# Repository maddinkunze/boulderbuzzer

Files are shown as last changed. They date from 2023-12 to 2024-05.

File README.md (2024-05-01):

# boulderbuzzer - Buzzers that can be mounted to (portable) boulder walls

This repository contains information, source code, pcb designs, assembly instructions, etc for building the following buzzers:

Those buzzers are designed around hollow M10 bolts that can be used to simultaneously mount the buzzer to a (in my case portable) boulder wall whilst allowing power cables to pass through the back and neatly hidden away.

## Buzzer

The [buzzer subdirectory](buzzer) contains some docs, the pcb design, the source code, some 3d-printable files and a few words about assembly, disassembly and repair for/of an individual buzzer.

## Station

The [station subdirectory](station) contains the documentation and source code for the base station to which all buzzers connect.

## Troubleshooting

1. **General:** What seems to be faulty?
   - Power Supply: Replace your power supply. It should provide 4.5V-5.5V and at least 0.5A + anything you want to switch on when pressing a buzzer (external ports). If possible, only connect one thing per power supply
   - Station: Repair the station as described here: [TODO]
   - All Buzzers: It is probably the station, do what the option "Station" says
   - One Buzzer: Go to step 2 (Buzzer/Startup)
2. **Buzzer/Startup:** Which color(s) does the buzzer have when power is supplied?
   - None: The buzzer (specifically the power plug/cable, the voltage regulator or the microcontroller) is probably faulty, go to step 3 (Buzzer/Faulty)
   - Blue (pulsating): Try to restart the station by unplugging it. It still does not work? The station is probably faulty, go back to step 1 (General)
   - Green (3 blinks): The buzzer is connected, go to step 4 (Buzzer/Press)
3. **Buzzer/Faulty:** Unplug everything and only plug in the station and the one "faulty" buzzer. Try to use the power cable of a different buzzer. Does the buzzer behave differently?
   - Yes: Go to step 2 (Buzzer/Startup). You have been here already and are going around in circles? Do what the option "No" says.
   - No: The buzzer is probably faulty. Repair the buzzer as described [here](buzzer#disassembly-and-repair)
4. **Buzzer/Press:** Press the buzzer after it is connected. What happens?
   - Nothing: the buzzer (specifically the microcontroller or button) is probably faulty, go to step 3 (Buzzer/Faulty)
   - It blinks red for half a second and turns off: There is probably another buzzer active and the game is working as intended. You have checked that already and it is not the intended behaviour (i.e. only one buzzer connected)? Then go to step 3 (Buzzer/Faulty)
   - It or another buzzer turned on or changed color: The buzzer probably works as intended. Go to step 5 (Buzzer/Working)
5. **Buzzer/Working:** Try to connect everything back one by one. Does it stop working at some point?
   - Yes: Inspect the last thing you've connected before it stopped working. Try to fix the last thing you've connected before it stopped working by going to step 1 (General). Did you try this with multiple things and at some random point it stopped working but it could not be associated with one specific device? Your power supply is probably not powerful enough. Go back to step 1 (General) and assume the power supply is the fault.
   - No: You've fixed it by restarting it i guess. Yay

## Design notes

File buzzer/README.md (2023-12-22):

# Buzzer

## Build Instructions

### Bill of Materials

| Amount | Part Name | DIY | Buy | Image | Additional Notes |
|---|---|---|---|---|---|
| $1 \times$ | Buzzer | ❌ | https://www.amazon.com/dp/B0CPHT5N3X <br> https://www.ebay.com/itm/395040810324 <br> https://www.amazon.com/dp/B0CGHFH3M1 <br> https://www.amazon.com/dp/B0CQSXBK7R <br> https://www.sparkfun.com/products/9181 <br> https://grobotronics.com/big-dome-push-button-red-100mm.html?sl=en <br> https://www.sparkfun.com/products/retired/11964 | | Preferrably with a transparent or white dome
| $1 \times$ | Buzzer Case | Click here | ❌ | | May not be neccessary, you can repurpose the outer shell of the buzzer
| $1 \times$ | 3D-Printed Bolt Holder | Click here | Can be ordered online using the design files | | Can be omitted in certain cases, should match the type of hollow M10 Bolt you are using
| $1 \times$ | M10 $\times$ 30mm Bolt (Hollow) | Click here | https://www.amazon.de/dp/B0BRNBQY3Y <br> https://www.ebay.com/itm/143405833724 | |
| $2 \times$ | M3 $\times$ 10mm Bolt (countersunk) |
| $2 \times$ | M3 $\times$ 12mm Bolt (countersunk) |
| $2 \times$ | M3 Nut |
| $2 \times$ | M3 Washer |
| $2 \times$ | M3 Rivet Nut | Click here | https://www.amazon.com/dp/B0962QQGFZ <br> https://www.ebay.com/itm/151788854026 | | Should have a height of at least [TODO]mm (so that the spring has enough room for actually compressing so the buzzer can be pressed)
| $2 \times$ | $6-8mm \times 14-20mm$ Compression Spring | Click here | | | The springs of some battery terminals work quite well here
| $1 \times$ | Custom PCB | Click here | The custom PCB can be ordered online (non-exhaustive list) from: <br> https://pcbway.com/ <br> https://jlcpcb.com/
| $2 \times$ | ESP-01S Module | ❌ | https://www.amazon.com/dp/B09J2KPHTN <br> https://www.ebay.com/itm/334980650665 | | An ESP-01S is preferred over an ESP-01, but both can be used
| $1 \times$ | AMS1117-3.3V Voltage Regulator (SMD) | ❌ | https://www.amazon.com/dp/B07X75XXYL <br> https://www.ebay.com/itm/392097419034
| $2 \times$ | RGB LED (5050 SMD) | ❌ | https://www.amazon.com/dp/B01CUGABPU <br> https://www.ebay.com/itm/191674244800 | | The RGB LEDs should not have a common cathode, having individual anodes for each internal LED is preferred but not neccessary; WS2812B and other addressable LEDs are **NOT** supported by my PCB design
| $2 \times$ | 100 - 200 $\Omega$ Resistor (THT)
| $1 \times$ | 120 - 220 $\Omega$ Resistor (THT)
| $1 \times$ | 3.3 - 10 $k\Omega$ Resistor (THT)
| $1 \times$ | 2 Pin, 3.5mm Pitch Screw Terminal (THT) | ❌ | https://www.amazon.com/dp/B07B791NMQ <br> https://www.ebay.com/itm/195773785709 <br> https://www.ebay.com/itm/314913808536 | | This can be omitted when soldering the power cable directly to the PCB; a larger or smaller pitch terminal can be used by changing the pcb design files
| $2 \times$ | 4 Pin, 2.54mm Pitch Round Female Pin Header/Socket (THT) | ❌ | https://www.amazon.com/dp/B0778TFL39 <br> https://www.ebay.com/itm/285532509511 <br> https://www.ebay.com/itm/196038438582 | | This can be omitted or replaced with other types of headers; in _both_ cases the pcb design should be changed
| $1 \times$ | $5.5mm \times 2.1mm$ DC Power Plug | ❌ | https://www.amazon.com/dp/B07Y8M8TWM <br> https://www.ebay.com/itm/114822858070 | | You can chose any plug you want, bear in mind that the plug has to fit through the same $\varnothing 10mm$ hole as the bolt
| $20cm$ | Flexible Power Cable
| $3cm$ | $\varnothing 9-14mm$ Heatshrink | | | | The heatshrink is only needed when removing the cover of your DC plug
| $5ml$ | White (Acrylic) Paint

### Required Tools
 - Screwdriver
   - Bit for your M3 Bolts
   - Bit for your screw terminal (optional)
 - Power Drill
   - 3mm Drill Bit
   - 10mm Drill Bit
 - Paint Brush
 - Soldering Iron + Solder
 - Pair of Pliers (probably)

## Assembly

[TODO]

## Disassembly and Repair

The buzzer contains moving/compliant parts and will be subject to breaking eventually. Here is how you can disassemble and repair the buzzer:

### 1. Undo the marked bolts

When you turn the buzzer around to the side where the cable comes out, there should be 4 bolts and whoever assembled it marked two opposing bolts. Undo these two bolts; the dome/springy part of the buzzer can now be taken out by pushing the hollow bolt/cable through the hole.

### 2. Take off the dome

Take a slim screwdriver or something else to pry and stick it between the lower and upper white parts. Use the screwdriver to pry these two pieces apart. You should be able to see a PCB now.

### 3. Take out the PCB

If possible, detach the power cable by unscrewing the bolts in the terminal block. Undo the two bolts securing the PCB to those long rivet nuts. Make sure you do not lose the rivet nuts or springs. Ideally, you now have only the PCB left and can start to test or resolder any component.

### 4. Take off the microcontroller

Should you need to take out the microcontroller (the extra pcb that kind of sticks up in the air), use pliers to gently wiggle it out of its socket. Try not to bend any of its pins. You can test and/or reprogram the microcontroller (look up "ESP-01" for more information) using the Arduino IDE.

### 5. Find the destroyed component

Please refer to the schematic [below](#schematic) on how the PCB should work and which component is broken. More information can be found in the pcb subdirectory.

Common faults are:
 - lose power connection
 - broken switch (check for continuity across the switch)
 - lose connection between the ESP01 and its socket (try to power the whole PCB and gently wiggle the ESP; if the LEDs start to flicker, try to push the ESP back into its socket)
 - corrosion
 - faulty LED (check them using a diode tester)
 - faulty resistors (simply measure them and check with the schematic)
 - faulty voltage regulator AMS1117-3.3 (check if there are 3.3V between the middle pin of the regulator and GND)

Please note that although the ESP01/ESP8266 works with 3.3V, the LEDs are supplied with 5V. This is normal and _not_ a fault.

### 6. Repair the destroyed component

Please refer to the bill of materials above for all the components used and where to find replacements.

### 7. Reassemble

You can now reassemble the buzzer as described in the Assembly section, starting at [TODO]

## Schematic
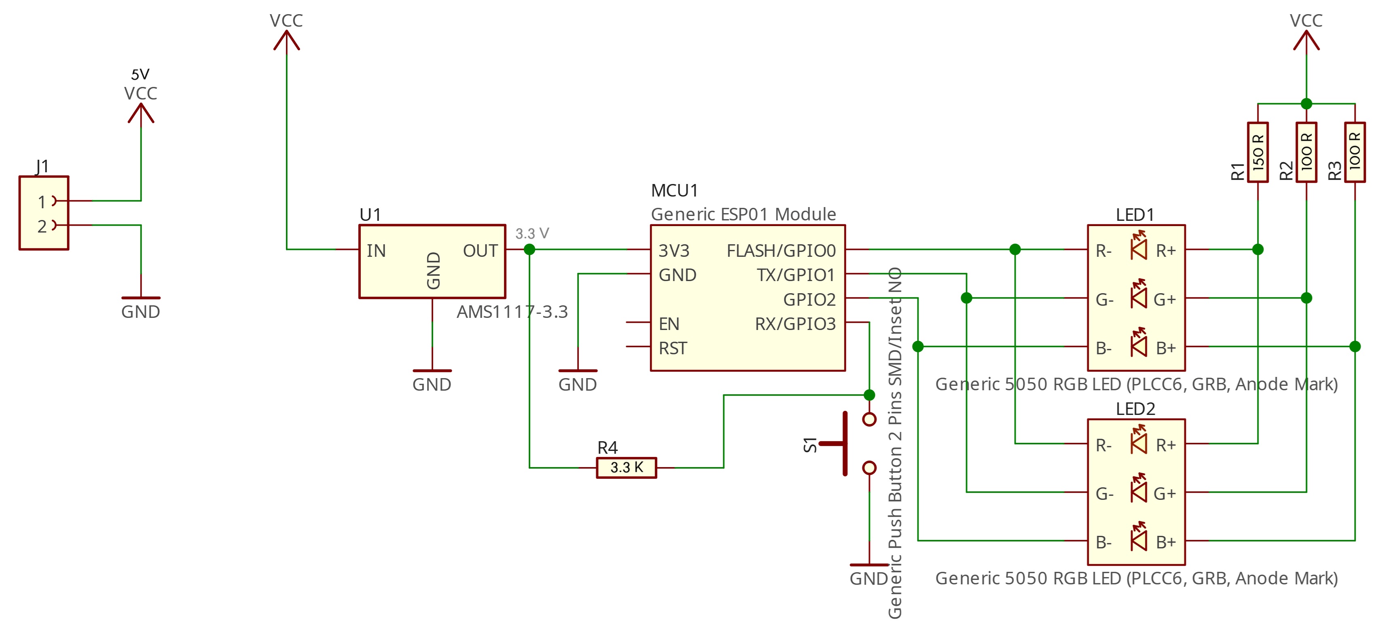
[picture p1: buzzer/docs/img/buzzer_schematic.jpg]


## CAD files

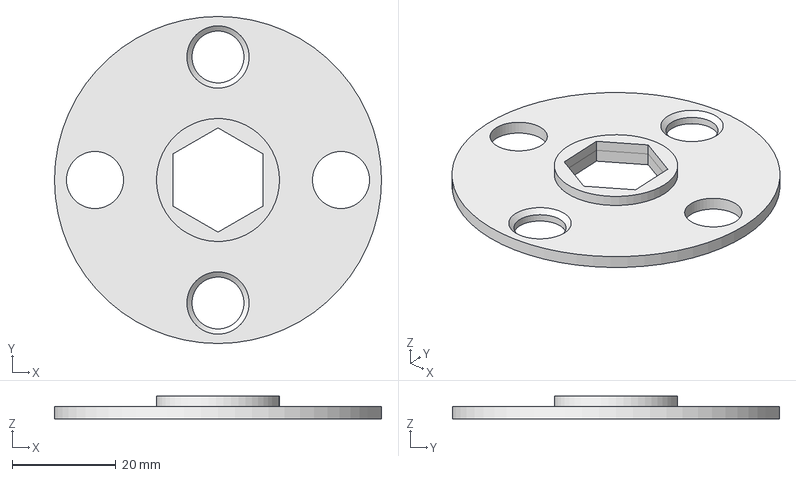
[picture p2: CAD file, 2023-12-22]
buzzer/parts/m10boltholder/boltholder.FCStd
63.0 x 63.0 x 4.40 mm

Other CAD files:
buzzer/parts/m10boltholder/boltholder.stl

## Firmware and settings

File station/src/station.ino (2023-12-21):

#ifdef ESP32
  #include <esp_now.h>
  #include <WiFi.h>
  #include <esp_wifi.h>
#else
  #include "espnow.h"
  #include <ESP8266WiFi.h>
#endif
#include "Wire.h"
#include "Adafruit_GFX.h"
#include "Adafruit_SSD1306.h"


#define DEBUG 1

uint8_t mac[] = {0xa8, 0x48, 0xfa, 0xff, 0xb6, 0x2b};

typedef enum {
  BW_CONNECT = 1,
  BW_UPDATE = 2,
  BW_KEEPALIVE = 3,
} bwCommand_t;

typedef enum {
  BW_STATION = 1,
  BW_BUTTON = 2,
  BW_LED_BUTTON = 3,
  BW_RGB_BUTTON = 4,
  BW_MAX_DEVICE
} bwDeviceType_t;

typedef enum {
  BW_RED = 'r',
  BW_GREEN = 'g',
  BW_BLUE = 'b',
  BW_PRESSED = 'P',
  BW_RELEASED = 'R',
} bwUpdateType_t;

typedef struct {
  bwDeviceType_t type;
  unsigned long lastSeen;
  uint8_t red;
  uint8_t blue;
  uint8_t green;
  unsigned long resetIn;
  unsigned long pressed;
  unsigned long nextUpdate;
  uint8_t mac[6];
} bwDevice_t;

#define BW_DEVICES 20
bwDevice_t bwDevices[BW_DEVICES];
size_t numBwDevices = 0;

#define SCREEN_WIDTH 128
#define SCREEN_HEIGHT 64
#define OLED_RESET     -1
#define SCREEN_ADDRESS 0x3C
Adafruit_SSD1306 display(SCREEN_WIDTH, SCREEN_HEIGHT, &Wire, OLED_RESET);

#define PIN_OUTPUT 15
#define TIME_OUTPUT_ON 1200
unsigned long timeOutputOff = 0;

#ifndef ERR_OK
#define ERR_OK 0
#endif

typedef enum {
  DISPLAY_STATS,
  SELECT_GAME,
  SETTINGS
} bwControlMode_t;
bwControlMode_t bwControlMode;

typedef enum {
  GAME_REACTION = 1,
  GAME_MAX
} bwControlGame_t;
int bwControlGame = GAME_REACTION;

int rotaryEncoderLast = 0;
unsigned long displayLastUpdate = 0;

int reactionLastButton = -1;
void reactionButtonPressed(int pressedButton) {
  if ((reactionLastButton >= 0) && (pressedButton != reactionLastButton)) {
    bwDevices[pressedButton].red = 160;
    bwDevices[pressedButton].green = 0;
    bwDevices[pressedButton].blue = 0;
    bwDevices[pressedButton].nextUpdate = 0;
    bwDevices[pressedButton].resetIn = millis() + 300;
    return;
  }

  reactionButtonNext();
}

void reactionButtonNext() {
  unsigned long timeNow = millis();
  int devicesOnline = 0;
  int devicesOnlineWithoutLast = 0;
  for (int i=0; i<numBwDevices; i++) {
    if ((timeNow - bwDevices[i].lastSeen) > 3000) { continue; }
    devicesOnline++;
    if (i == reactionLastButton) { continue; }
    devicesOnlineWithoutLast++;
  }

  if (reactionLastButton >= 0) {
    bwDevices[reactionLastButton].red = 0;
    bwDevices[reactionLastButton].green = 0;
    bwDevices[reactionLastButton].blue = 0;
    bwDevices[reactionLastButton].nextUpdate = 0;
  }

  if (!devicesOnlineWithoutLast) {
    setButtonRandomColor(reactionLastButton);
    return;
  }

  if (!devicesOnline) { reactionLastButton = -1; return; }
  int nextButton = random(devicesOnlineWithoutLast) + 1;
  int nextButtonIndex = -1;
  while (nextButton && (nextButtonIndex < (int)numBwDevices)) {
    nextButtonIndex++;
    if ((timeNow - bwDevices[nextButtonIndex].lastSeen) > 3000) { continue; }
    if (nextButtonIndex == reactionLastButton) { continue; }
    nextButton--;
  }

  if ((nextButtonIndex < 0) || (nextButtonIndex >= numBwDevices)) {
    reactionLastButton = -1;
    return;
  }

  setButtonRandomColor(nextButtonIndex);
  reactionLastButton = nextButtonIndex;
}

void setButtonRandomColor(int buttonIndex) {
  if (buttonIndex < 0) { return; }
  bwDevice_t& bwDevice = bwDevices[buttonIndex];
  bwDevice.red = 0;
  bwDevice.green = 0;
  bwDevice.blue = 0;
  switch (random(22)) {
    case 0: // RED
      bwDevice.red = 255;
      break;
    case 1: // GREEN
      bwDevice.green = 255;
      break;
    case 2: // BLUE
      bwDevice.blue = 255;
      break;
    case 3: // PURPLE
    case 4:
    case 5: // (3x probability)
      bwDevice.red = 255;
      bwDevice.blue = 220;
      break;
    case 6: // YELLOW
      bwDevice.red = 255;
      bwDevice.green = 180;
      break;
    case 7: // LIGHTER YELLOW
      bwDevice.red = 255;
      bwDevice.green = 220;
      break;
    case 8: // TURQOISE
    case 9: // (2x probability)
      bwDevice.green = 255;
      bwDevice.blue = 255;
      break;
    case 10: // PINK
    case 11: // (2x probability)
      bwDevice.red = 255;
      bwDevice.blue = 110;
      break;
    case 12: // ORANGE
    case 13: // (2x probability)
      bwDevice.red = 255;
      bwDevice.green = 40;
      break;
    case 14: // LIGHT TURQOISE
    case 15:
    case 16: // (3x probability)
      bwDevice.green = 255;
      bwDevice.blue = 120;
      break;
    case 17: // LIGHT BLUE
    case 18: // (2x probability)
      bwDevice.green = 120;
      bwDevice.blue = 255;
      break;
    case 19: // COLD WHITE
      bwDevice.red = 220;
      bwDevice.green = 220;
      bwDevice.blue = 255;
      break;
    case 20: // NEUTRAL WHITE
      bwDevice.red = 255;
      bwDevice.green = 240;
      bwDevice.blue = 180;
      break;
    case 21: // WARM WHITE
      bwDevice.red = 255;
      bwDevice.green = 150;
      bwDevice.blue = 60;
      break;
  }
  bwDevice.nextUpdate = 0;
}

void updateGame() {
  unsigned long timeNow = millis();
  switch (bwControlGame) {
    case GAME_REACTION:
      if ((reactionLastButton >= 0) && ((timeNow - bwDevices[reactionLastButton].lastSeen) > 5000)) { reactionButtonNext(); }
      break;
  }
}

void updateDevices() {
  for (int i=0; i<numBwDevices; i++) {
    updateDevice(i);
  }
}

void updateDevice(int numDevice) {
  unsigned long timeNow = millis();
  
  if (bwDevices[numDevice].pressed && ((timeNow - bwDevices[numDevice].pressed) > 2000)) {
    bwDevices[numDevice].pressed = 0;
    handleButtonRelease(numDevice);
  }

  if (bwDevices[numDevice].resetIn && (timeNow > bwDevices[numDevice].resetIn)) {
    bwDevices[numDevice].resetIn = 0;
    bwDevices[numDevice].red = 0;
    bwDevices[numDevice].green = 0;
    bwDevices[numDevice].blue = 0;
    bwDevices[numDevice].pressed = 0;
    bwDevices[numDevice].nextUpdate = 0;
  }

  if (bwDevices[numDevice].nextUpdate > timeNow) { return; }
  size_t len = 0;
  uint8_t data[32];
  data[len++] = BW_UPDATE;
  switch (bwDevices[numDevice].type) {
    case BW_RGB_BUTTON:
      data[len++] = BW_RED;
      data[len++] = bwDevices[numDevice].red;
      data[len++] = BW_GREEN;
      data[len++] = bwDevices[numDevice].green;
      data[len++] = BW_BLUE;
      data[len++] = bwDevices[numDevice].blue;
      break;
    default:
      break;
  }
  sendData(bwDevices[numDevice].mac, data, len);
  bwDevices[numDevice].nextUpdate = timeNow + 1000;
}

void initControls() {
#if (DEBUG)
  Serial.begin(115200);
#endif
  if (!display.begin(SSD1306_SWITCHCAPVCC, SCREEN_ADDRESS)) {
#if (DEBUG)
    Serial.println("Could not initialize display!");
#endif
  }
  bwControlMode = DISPLAY_STATS;
  updateDisplay();

  
  pinMode(0, INPUT_PULLUP);
  pinMode(2, INPUT_PULLUP);
  pinMode(14, INPUT_PULLUP);
  attachInterrupt(digitalPinToInterrupt(2), rotaryEncoderRotate, FALLING);
  attachInterrupt(digitalPinToInterrupt(14), rotaryEncoderRotate, FALLING);
}

ICACHE_RAM_ATTR void rotaryEncoderRotate() {
  if (millis() < rotaryEncoderLast + 100) { return; }
  rotaryEncoderLast = millis();
  bwControlGame += digitalRead(0) ? -1 : 1;
  if (bwControlGame < 1) { bwControlGame = 1; }
  if (bwControlGame >= GAME_MAX) { bwControlGame = GAME_MAX-1; }
  displayLastUpdate = 0;
}

ICACHE_RAM_ATTR void rotaryEncoderClick() {
  
}

void updateDisplay() {
  updateDisplay(bwControlMode);
}

void updateDisplay(int modeUpdate) {
  return;
  if (bwControlMode != modeUpdate) { return; }

  unsigned long timeNow = millis();

  display.clearDisplay();
  switch (bwControlMode) {
   case DISPLAY_STATS:
    display.setTextSize(1);
    display.setTextColor(WHITE);
    display.setCursor(0, 0);
    display.print("Devices: ");
    int devicesConnected = 0;
    for (int i=0; i<numBwDevices; i++) {
      if ((timeNow - bwDevices[i].lastSeen) > 3000) { continue; }
      devicesConnected++;
    }
    display.print(devicesConnected);
    display.print("/");
    display.print(numBwDevices);
    display.print("/");
    display.println(BW_DEVICES);
    display.print("Game/Mode: ");
    switch (bwControlGame) {
     case GAME_REACTION:
      display.print("Reaction");
      break;
     default:
      display.print("Invalid");
    }
  }
  display.display();
}

void sendData(const uint8_t* macAddress, const uint8_t* data, uint8_t length) {
  esp_now_send(macAddress, data, length);
#if DEBUG
  Serial.print("Sent Data via ESP_NOW to ");
  for (uint8_t i=0; i<6; i++) {
    if (i) { Serial.print(":"); }
    if (!(macAddress[i]&0xF0)) { Serial.print("0"); }
    Serial.print(macAddress[i], HEX);
  }
  Serial.print(" containing \"");
  Serial.write(data, length);
  Serial.println("\"");
#endif
}

#ifdef ESP32
  esp_now_peer_info_t peerToAdd;
#endif
int addPeer(const uint8_t* mac) {
#ifdef ESP32
  memcpy(peerToAdd.peer_addr, mac, 6);
  peerToAdd.channel = 0;
  peerToAdd.encrypt = false;
  return esp_now_add_peer(&peerToAdd);
#else
  return esp_now_add_peer(mac, ESP_NOW_ROLE_COMBO, 0, NULL, 0);
#endif
}

void addDevice(const uint8_t* macAddress, uint8_t deviceType) {
  if (numBwDevices >= BW_DEVICES) { return; }
  if (deviceType < 1) { return; }
  if (deviceType > BW_MAX_DEVICE) { return; }
  bwDevices[numBwDevices].type = (bwDeviceType_t)deviceType;
  bwDevices[numBwDevices].lastSeen = millis();
  memcpy(bwDevices[numBwDevices].mac, macAddress, 6);
  bwDevices[numBwDevices].red = 0;
  bwDevices[numBwDevices].green = 0;
  bwDevices[numBwDevices].blue = 0;
  bwDevices[numBwDevices].pressed = 0;
  
  int error = addPeer(bwDevices[numBwDevices].mac);
  if (error) { return; }
  uint8_t data[2] = {BW_CONNECT, BW_STATION};
  sendData(macAddress, data, 2);
  numBwDevices++;
  displayLastUpdate = 0;
}

void onDataReceiveESP32(const uint8_t* macAddress, const uint8_t* data, int length) {
  onDataReceive(macAddress, data, (uint8_t)length);
}

void onDataReceive(const uint8_t* macAddress, const uint8_t* data, uint8_t length) {
#if (DEBUG)
  Serial.print("Received Data via ESP_NOW from ");
  for (uint8_t i=0; i<6; i++) {
    if (i) { Serial.print(":"); }
    if (!(macAddress[i]&0xF0)) { Serial.print("0"); }
    Serial.print(macAddress[i], HEX);
  }
  Serial.print(" containing \"");
  Serial.write(data, length);
  Serial.println("\"");
#endif

  int numDevice;
  for (uint8_t i=0; i<numBwDevices; i++) {
    if (strncmp((char*)macAddress, (char*)bwDevices[i].mac, 6)) { continue; }
    numDevice = i;
    break;
  }

  bwDevices[numDevice].lastSeen = millis();

  if (length < 1) { return; }

  switch (data[0]) {
    case BW_CONNECT:
      if (length != 2) { return; }
      addDevice(macAddress, data[1]);
      break;
    case BW_UPDATE:
      if (length < 2) { return; }
      switch (data[1]) {
        case BW_PRESSED:
          bwDevices[numDevice].pressed = millis();
          handleButtonPress(numDevice);
          break;
        case BW_RELEASED:
          bwDevices[numDevice].pressed = 0;
          handleButtonRelease(numDevice);
          break;
        default:
          break;
      }
      break;
    default:
      return;
  }
}

void handleButtonPress(int numDevice) {
  digitalWrite(PIN_OUTPUT, HIGH);
  timeOutputOff = millis() + TIME_OUTPUT_ON;
}

void handleButtonRelease(int numDevice) {
  switch (bwControlGame) {
    case GAME_REACTION:
      reactionButtonPressed(numDevice);
      break;
  }
}

void initConnections() {
  WiFi.mode(WIFI_STA);
  WiFi.disconnect();

  esp_wifi_set_mac(WIFI_IF_STA, mac);
  
  if (esp_now_init() != ERR_OK) { 
    // TODO show error
    return;
  }
  
#ifdef ESP32
  esp_now_register_recv_cb(onDataReceiveESP32);
#else
  esp_now_set_self_role(ESP_NOW_ROLE_COMBO);
  esp_now_register_recv_cb(onDataReceive);
#endif
  
}

void initPins() {
  pinMode(PIN_OUTPUT, OUTPUT);
}

void setup() {
  // put your setup code here, to run once:
  initControls();
  initConnections();
  initPins();
}

void loop() {
  unsigned long timeNow = millis();
  updateDevices();
  updateGame();
  if (timeNow - displayLastUpdate > 3000) {
    updateDisplay();
    displayLastUpdate = timeNow;
  }
  if (timeOutputOff && (timeNow > timeOutputOff)) {
    timeOutputOff = 0;
    digitalWrite(PIN_OUTPUT, LOW);
  }
}

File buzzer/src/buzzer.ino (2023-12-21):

#include "espnow.h"
#include "ESP8266WiFi.h"

uint8_t mac[] = {0xa8, 0x48, 0xfa, 0xff, 0xb6, 0x2b};

typedef enum {
  BW_CONNECT = 1,
  BW_UPDATE = 2,
  BW_KEEPALIVE = 3,
} bwCommand_t;

typedef enum {
  BW_STATION = 1,
  BW_BUTTON = 2,
  BW_LED_BUTTON = 3,
  BW_RGB_BUTTON = 4,
  BW_MAX_DEVICE
} bwDeviceType_t;

typedef enum {
  BW_RED = 'r',
  BW_GREEN = 'g',
  BW_BLUE = 'b',
  BW_PRESSED = 'P',
  BW_RELEASED = 'R',
} bwUpdateType_t;

int pinRed = 0;
int pinGreen = 1;
int pinBlue = 2;
int pinButton = 3;
#define PENDINGLED pinBlue
#define SUCCESSLED pinGreen
#define ERRORLED pinRed

unsigned long lastButtonPress = 0;
unsigned long lastUpdate = 0;

void updateValues(uint8_t* data, uint8_t length) {
  uint8_t i=0;
  while (i<length) {
    switch (data[i]) {
      case BW_RED:
        analogWrite(pinRed, 255-data[++i]);
        break;
      case BW_GREEN:
        analogWrite(pinGreen, 255-data[++i]);
        break;
      case BW_BLUE:
        analogWrite(pinBlue, 255-data[++i]);
        break;
      default:
        return;
    }
    i++;
  }
}

bwUpdateType_t lastState = BW_RELEASED;
ICACHE_RAM_ATTR void onButtonPress() {
  unsigned long _lastButtonPress = lastButtonPress;
  lastButtonPress = millis();
  if (lastButtonPress - _lastButtonPress < 10) { return; }
  switch (lastState) {
    case BW_RELEASED:
      lastState = BW_PRESSED;
      break;
    default:
      lastState = BW_RELEASED;
      break;
  }
  uint8_t data[] = {BW_UPDATE, lastState};
  sendData(mac, data, 2);
}

void onDataReceive(uint8_t* macAddress, uint8_t* data, uint8_t length) {
  lastUpdate = millis();
  if (length < 1) { return; }
  switch (data[0]) {
    case BW_CONNECT:
    case BW_KEEPALIVE:
      break;
    case BW_UPDATE:
      updateValues(data+1, length-1);
      break;
    default:
      return;
  }
}

void sendData(uint8_t* macAddress, uint8_t* data, uint8_t length) {
  esp_now_send(macAddress, data, length);
}

unsigned long lastKeepalive = 0;
void sendKeepalive() {
  unsigned long timeNow = millis();
  if (timeNow - lastKeepalive < 800) { return; }
  uint8_t data[] = {BW_KEEPALIVE};
  sendData(mac, data, 1);
  lastKeepalive = timeNow;
}

bool isConnected(unsigned long threshold) {
  return lastUpdate && ((millis() - lastUpdate) < threshold);
}

void initConnections() {
  WiFi.mode(WIFI_STA);
  WiFi.disconnect();
  
  if (esp_now_init()) { 
    // TODO show error
    return;
  }
  
  esp_now_set_self_role(ESP_NOW_ROLE_COMBO);
  esp_now_register_recv_cb(onDataReceive);
  esp_now_add_peer(mac, ESP_NOW_ROLE_COMBO, 0, NULL, 0);
}

void initHardware() {
  pinMode(pinRed, OUTPUT);
  pinMode(pinGreen, OUTPUT);
  pinMode(pinBlue, OUTPUT);
  digitalWrite(pinRed, HIGH);
  digitalWrite(pinGreen, HIGH);
  digitalWrite(pinBlue, HIGH);
  pinMode(pinButton, INPUT_PULLUP);
  attachInterrupt(digitalPinToInterrupt(pinButton), onButtonPress, CHANGE);
}

void waitForConnection() {
  unsigned long timeStart = millis();
  unsigned long timeNow;
  unsigned long nTry = 0;
  unsigned long tTry = 500;
  uint8_t data[] = {BW_CONNECT, BW_RGB_BUTTON};
  while (true) {
    timeNow = millis();
    analogWrite(PENDINGLED, floor((cos(0.002 * (timeNow - timeStart)) + 1) * 127));
    if (isConnected(2000)) { break; }
    if (timeNow > timeStart + nTry * tTry) {
      sendData(mac, data, 2);
      nTry++;
    }
    delay(50);
  }

  digitalWrite(PENDINGLED, HIGH);
  
  for (uint8_t i=0; i<3; i++) {
    digitalWrite(SUCCESSLED, HIGH);
    delay(300);
    digitalWrite(SUCCESSLED, LOW);
    delay(300);
  }
  digitalWrite(SUCCESSLED, HIGH);
}

void setup() {
  // put your setup code here, to run once:
  initHardware();
  initConnections();
}

void loop() {
  // put your main code here, to run repeatedly:
  if (isConnected(5000)) { 
    sendKeepalive();
    return;
  }
  waitForConnection();
}

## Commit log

2023-12-21 added files for the buzzer pcb
    [CRi-CRi_Buzzer_COPPER-BOTTOM.gbr, CRi-CRi_Buzzer_COPPER-TOP.gbr, CRi-CRi_Buzzer_DRILLS.drl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]
2023-12-21 added source code for buzzer and station
    [buzzer.ino, station.ino]
2023-12-22 added 3d printable files for holding the hollow m10 bolt
    [boltholder.FCStd, boltholder.stl]
2023-12-22 added bom and tools for buzzer
2023-12-22 added common troubleshooting guide, added schematic image for buzzer, added disassembly and repair instructions for buzzer
